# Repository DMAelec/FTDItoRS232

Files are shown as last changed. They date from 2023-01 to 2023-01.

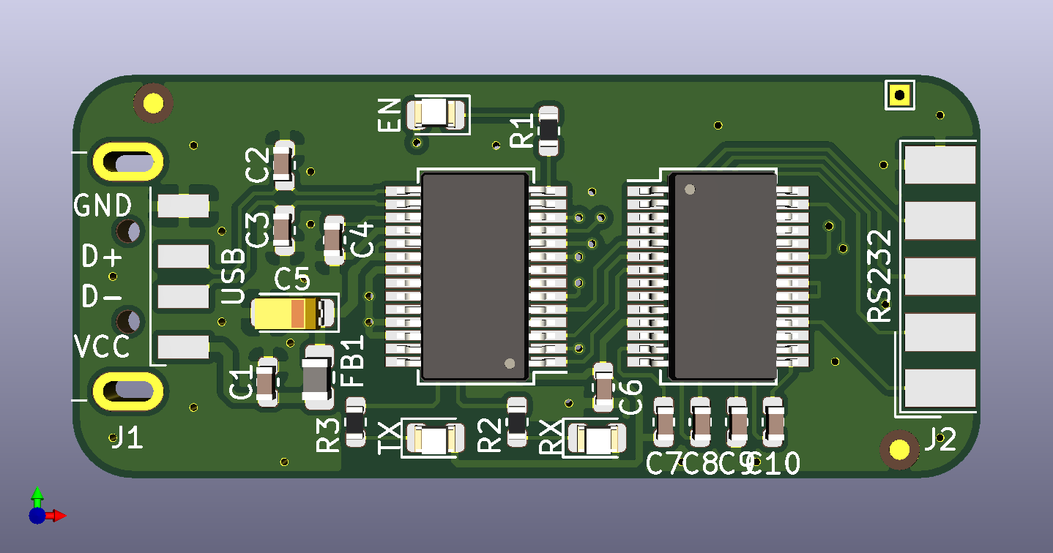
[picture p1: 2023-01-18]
FTDItoRS232-3DView.png

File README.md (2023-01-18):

# FTDItoRS232
An FTDI based USB to RS232 adapter that has a USB type A plug. This adapter has all the control signals wired up(RTS,CTS,DSR,DTR,CD,RI) with
pin 9(RI) on the DB-9 connector always active during standby.

This adapter is designed with KiCad ver 5.1 and has the gerbers located in the GERBER.zip folder. The bill of materials which contains
the part values and Digikey/Mouser part numbers are located in the BOM.txt file.

NOTE: It is recommended to use a PCB vendor that can produce 1.2mm boards in order to properly fit the DB-9 connector.
ALSO NOTE: This project utilizes mostly SMD parts and is for people with proper skills and tools for working with SMD.

Current Revision #2

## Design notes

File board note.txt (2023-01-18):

FTDItoRS232 MANUFACTURING NOTES

Layers: 2

Dimensions: 45*20

PCB Thickness: 1.2mm

PCB Soldermask: Green

Silkscreen: White

Surface Finish: HASL

Copper Weight: 1oz

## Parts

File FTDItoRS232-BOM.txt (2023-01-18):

REF			VALUE			PART NO.
----------------------------------------------------------------------
R1,R2,R3		470 Ohm			CRCW0603470RJNEAC

D1			LED GREEN		VFHD1112H-3B72B-TR

D2,D3			LED YELLOW		VFHY1112H-3BY2D-TR

C1			10nF CERAMIC		C0603C103J4RACTU

C2,C3			47pF CERAMIC		C0603C470F5GAC7411

C4,C6,C7,		100nF CERAMIC		C0603C104J4RAC7040
C8,C9,C10

C5			4.7uF TANTALUM		T491A475K010AT

FB1			220 Ohm FERRITE BEAD	BLM21BB221SN1D

Y1(REV 1)		12MHz CRYSTAL		445I32E12M00000

U1			FT232RL			FT232RL-REEL

U2			MAX213			SP213EHCA-L/TR

J1			CONN USB TYPE-A		1734028-1

J2			CONN DE9 MALE		5-747904-5

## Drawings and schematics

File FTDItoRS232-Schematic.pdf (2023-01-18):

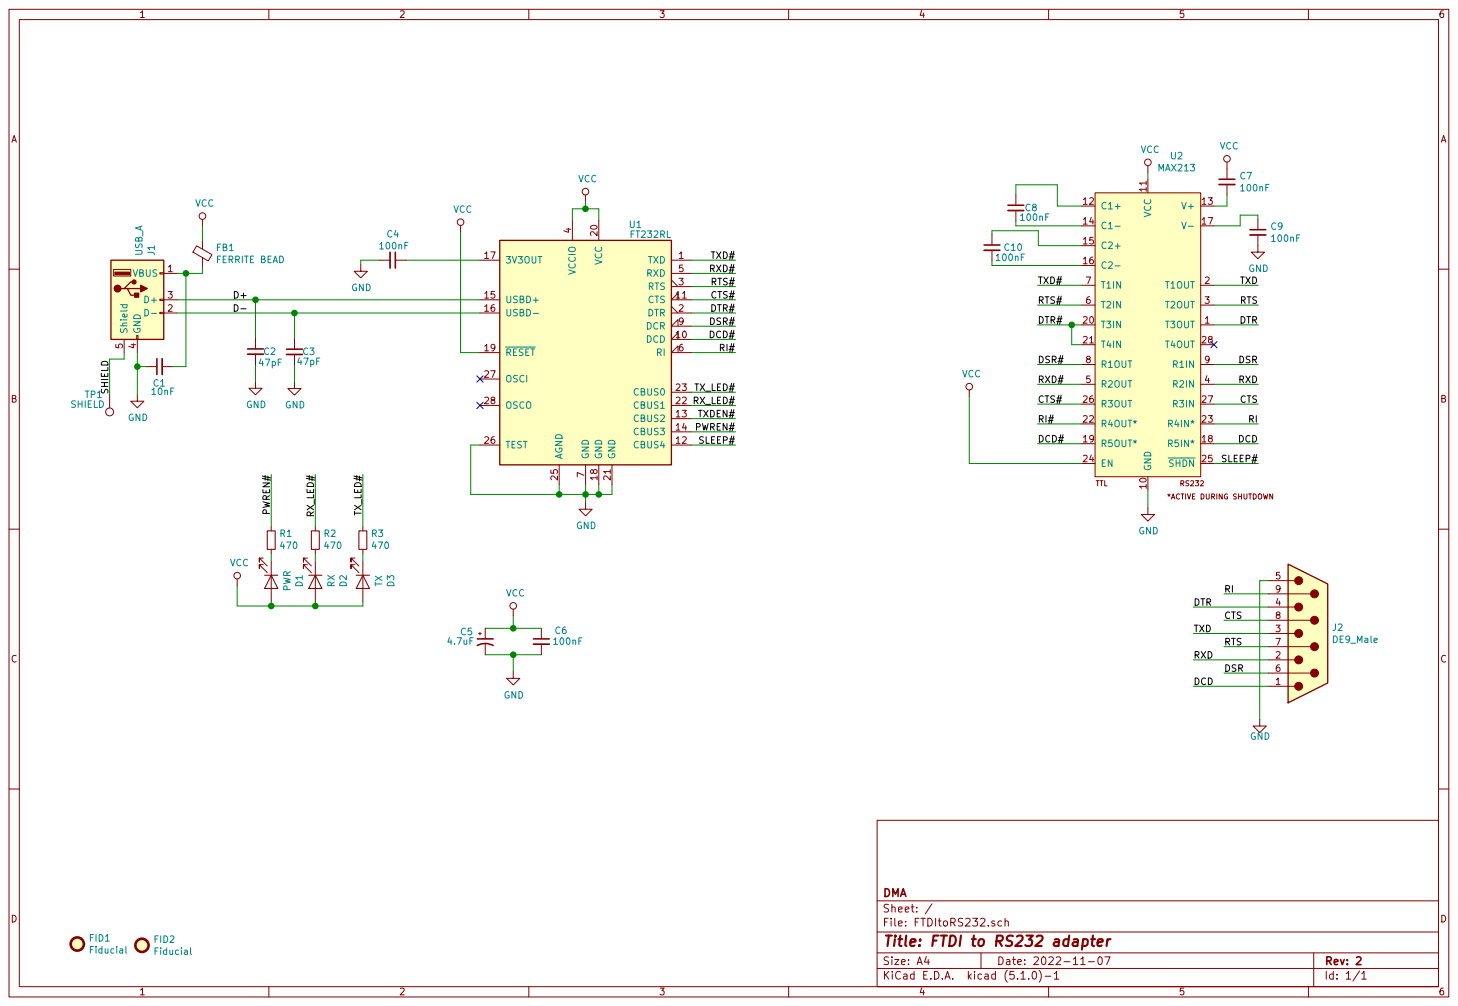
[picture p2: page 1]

7 DCR 9 U1FT232RL PWREN# TXDEN# SLEEP# RX_LED# TX_LED# VCC

RTS# DTR# CTS# DCD# RI# RXD# DCD# GND

RI CTS RTS DSR
DTR

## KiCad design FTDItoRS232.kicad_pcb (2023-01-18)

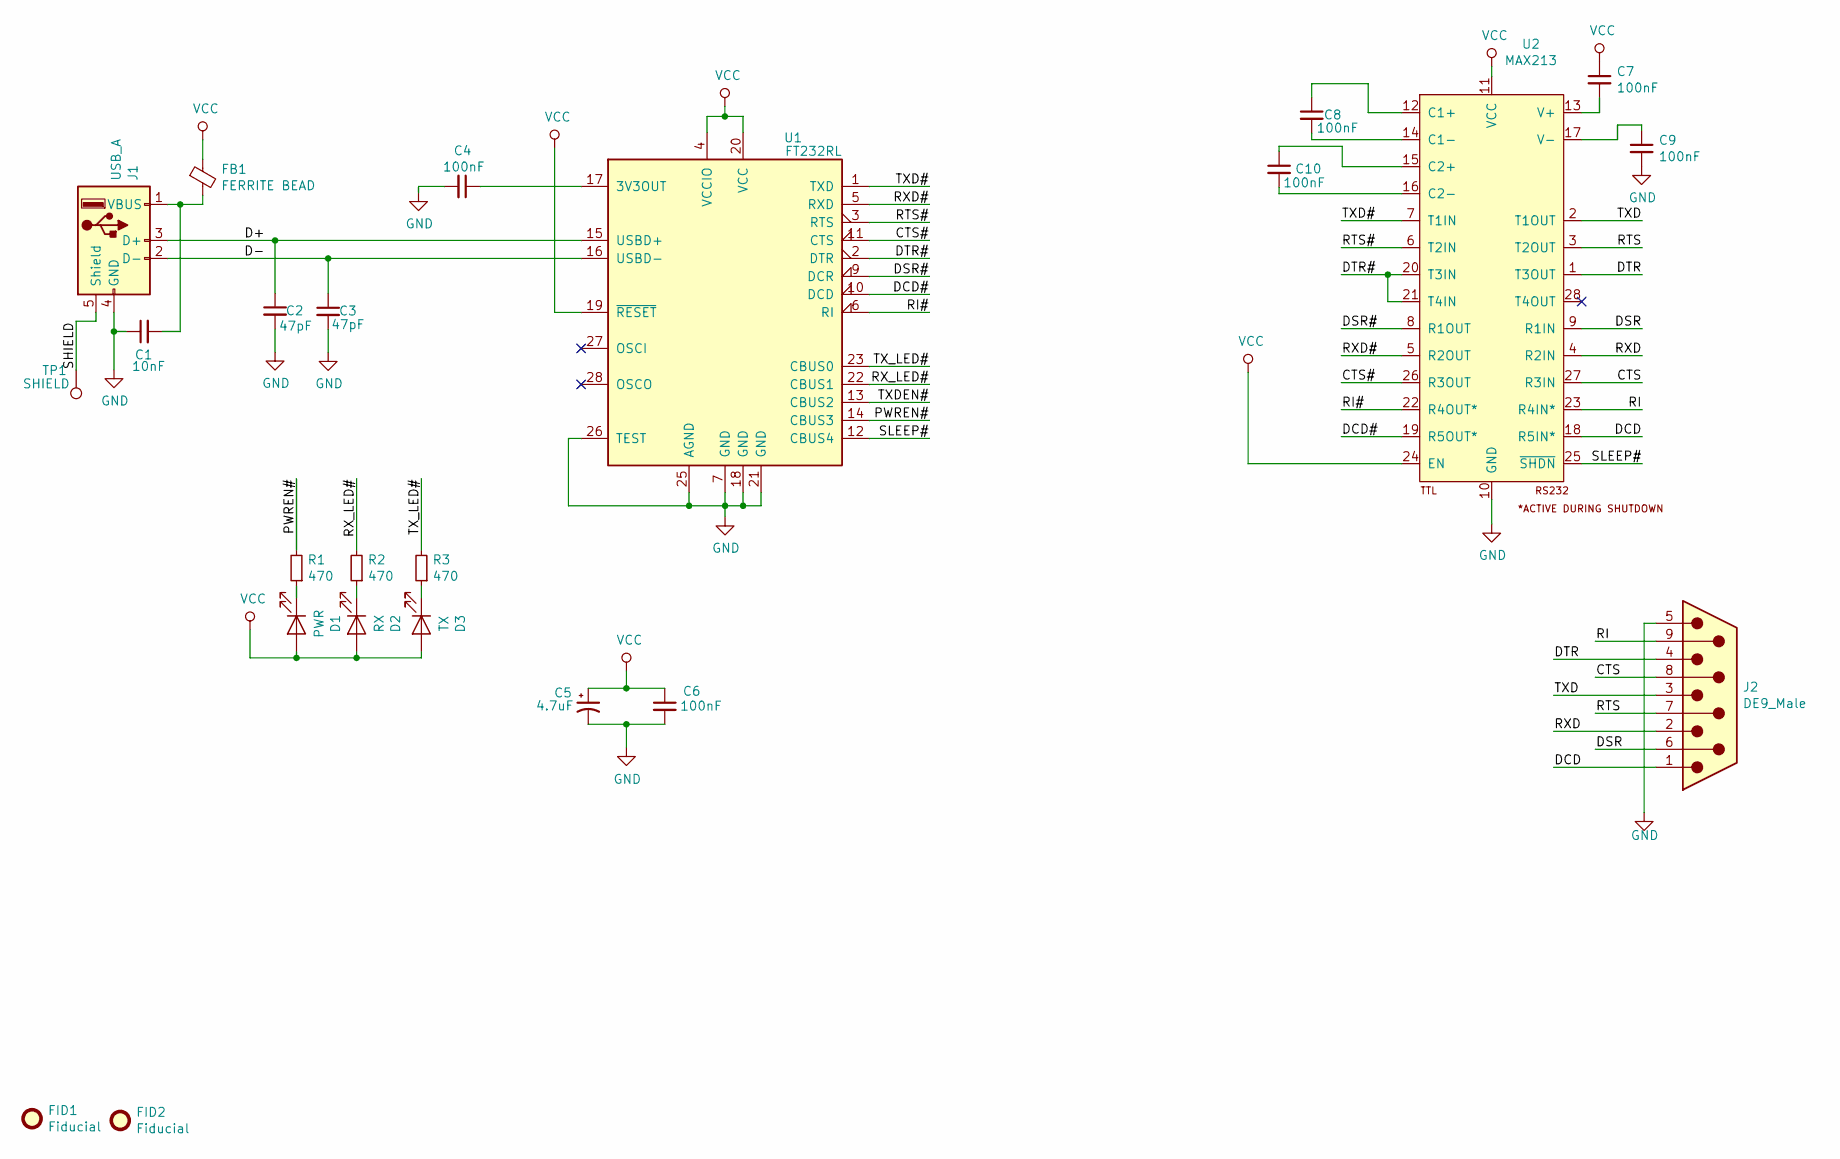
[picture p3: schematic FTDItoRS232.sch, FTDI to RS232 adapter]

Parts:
C1: 10nF; C_0603_1608Metric
C2, C3: 47pF; C_0603_1608Metric
C4, C6, C7, C8, C9, C10: 100nF; C_0603_1608Metric
C5: 4.7uF; CP_EIA-3216-18_Kemet-A
D1: PWR; LED_0805_2012Metric
D2: RX; LED_0805_2012Metric
D3: TX; LED_0805_2012Metric
FB1: FERRITE BEAD; L_0805_2012Metric_Pad1.15x1.40mm_HandSolder
FID1, FID2: Fiducial; Fiducial_1mm_Mask2mm
J1: USB_A; USB_A_Plug_Horizontal
J2: DE9_Male; DSUB-9_Male_EdgeMount_P2.77mm
R1, R2, R3: 470; R_0603_1608Metric
TP1: SHIELD; TestPoint_THTPad_1.0x1.0mm_Drill0.5mm
U1: FT232RL; SSOP-28_5.3x10.2mm_P0.65mm
U2: MAX213; SSOP-28_5.3x10.2mm_P0.65mm

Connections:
/CTS: J2.8, U2.27 (R3IN)
/CTS#: U1.11 (CTS), U2.26 (R3OUT)
/D+: C2.1, J1.3 (D+), U1.15 (USBD+)
/D-: C3.1, J1.2 (D-), U1.16 (USBD-)
/DCD: J2.1, U2.18 (R5IN*)
/DCD#: U1.10 (DCD), U2.19 (R5OUT*)
/DSR: J2.6, U2.9 (R1IN)
/DSR#: U1.9 (DCR), U2.8 (R1OUT)
/DTR: J2.4, U2.1 (T3OUT)
/DTR#: U1.2 (DTR), U2.20 (T3IN), U2.21 (T4IN)
/PWREN#: R1.2, U1.14 (CBUS3)
/RI: J2.9, U2.23 (R4IN*)
/RI#: U1.6 (RI), U2.22 (R4OUT*)
/RTS: J2.7, U2.3 (T2OUT)
/RTS#: U1.3 (RTS), U2.6 (T2IN)
/RXD: J2.2, U2.4 (R2IN)
/RXD#: U1.5 (RXD), U2.5 (R2OUT)
/RX_LED#: R2.2, U1.22 (CBUS1)
/SHIELD: J1.5 (Shield), TP1.1
/SLEEP#: U1.12 (CBUS4), U2.25 (~SHDN)
/TXD: J2.3, U2.2 (T1OUT)
/TXD#: U1.1 (TXD), U2.7 (T1IN)
/TXDEN#: U1.13 (CBUS2)
/TX_LED#: R3.2, U1.23 (CBUS0)
GND: C1.1, C2.2, C3.2, C4.2, C5.2, C6.2, C9.2, J1.4 (GND), J2.5, U1.7 (GND), U1.18 (GND), U1.21 (GND), U1.25 (AGND), U1.26 (TEST), U2.10 (GND)
unnamed: C1.2, FB1.2, J1.1 (VBUS)
unnamed: C4.1, U1.17 (3V3OUT)
unnamed: C7.2, U2.13 (V+)
unnamed: C8.1, U2.12 (C1+)
unnamed: C8.2, U2.14 (C1-)
unnamed: C9.1, U2.17 (V-)
unnamed: C10.1, U2.15 (C2+)
unnamed: C10.2, U2.16 (C2-)
unnamed: D1.1 (K), R1.1
unnamed: D2.1 (K), R2.1
unnamed: D3.1 (K), R3.1
VCC: C5.1, C6.1, C7.1, D1.2 (A), D2.2 (A), D3.2 (A), FB1.1, U1.4 (VCCIO), U1.19 (~RESET~), U1.20 (VCC), U2.11 (VCC), U2.24 (EN)

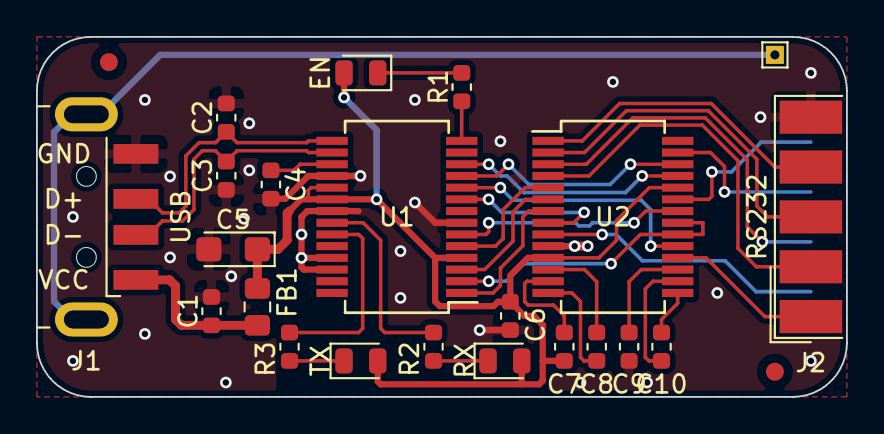
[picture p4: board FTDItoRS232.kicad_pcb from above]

Board: 2 copper layers, 45.0 x 20.0 mm, 24 parts (0 on the bottom side), 36 nets.
